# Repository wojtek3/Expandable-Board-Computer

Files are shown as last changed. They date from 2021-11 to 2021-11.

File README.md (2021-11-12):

# Board Computer display board

## General info
This project is a display for simple board computer dedicated for odl cars which didn't have it.

Board computer in Audi 80

## Base features
* ST7789 display
* EGT from K-type thermocouple
* AFR from analog input
* Control buttons
* I2C bus for more modules

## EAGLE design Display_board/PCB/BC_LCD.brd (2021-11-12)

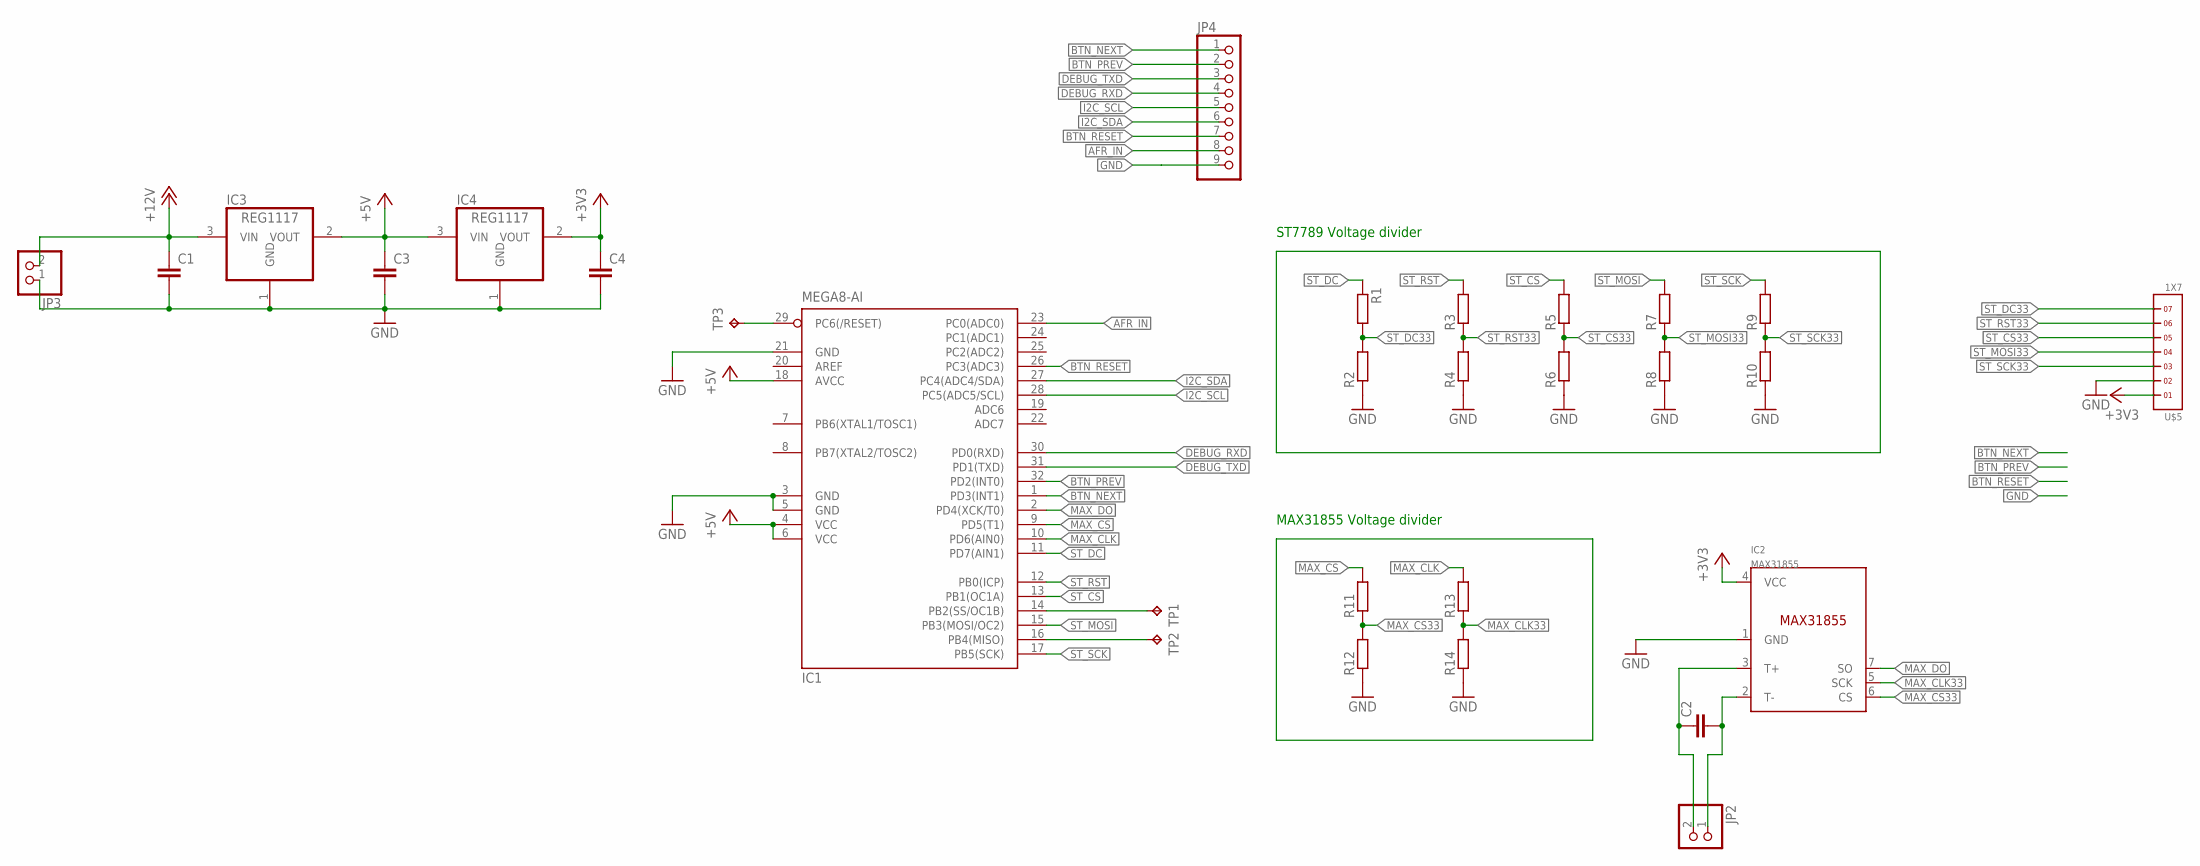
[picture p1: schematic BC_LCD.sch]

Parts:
C1, C2, C3, C4: C-EUC0805K; C0805K
IC1: MEGA8-AI; TQFP32-08
IC2: MAX31855; SOIC8
IC3, IC4: REG1117; SOT223
JP2, JP3: PINHD-1X2; 1X02
JP4: PINHD-1X9; 1X09
R1, R2, R3, R4, R5, R6, R7, R8, R9, R10, R11, R12, R13, R14: R-EU_M0805; M0805
TP1, TP2, TP3: TPTP12R; TP12R
U$5: 1X7

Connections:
+3V3: C4.1, IC2.4 (VCC), IC4.2 (VOUT), U$5.1
+5V: C3.1, IC1.4 (VCC), IC1.6 (VCC), IC1.18 (AVCC), IC3.2 (VOUT), IC4.3 (VIN)
+12V: C1.1, IC3.3 (VIN), JP3.2
AFR_IN: IC1.23 (PC0(ADC0)), JP4.8
BTN_NEXT: IC1.1 (PD3(INT1)), JP4.1
BTN_PREV: IC1.32 (PD2(INT0)), JP4.2
BTN_RESET: IC1.26 (PC3(ADC3)), JP4.7
DEBUG_RXD: IC1.30 (PD0(RXD)), JP4.4
DEBUG_TXD: IC1.31 (PD1(TXD)), JP4.3
GND: C1.2, C3.2, C4.2, IC1.3 (GND), IC1.5 (GND), IC1.21 (GND), IC2.1 (GND), IC3.1 (GND), IC4.1 (GND), JP3.1, JP4.9, R2.1, R4.1, R6.1, R8.1, R10.1, R12.1, R14.1, U$5.2
I2C_SCL: IC1.28 (PC5(ADC5/SCL)), JP4.5
I2C_SDA: IC1.27 (PC4(ADC4/SDA)), JP4.6
MAX_CLK: IC1.10 (PD6(AIN0)), R13.2
MAX_CLK33: IC2.5 (SCK), R13.1, R14.2
MAX_CS: IC1.9 (PD5(T1)), R11.2
MAX_CS33: IC2.6 (CS), R11.1, R12.2
MAX_DO: IC1.2 (PD4(XCK/T0)), IC2.7 (SO)
unnamed: C2.1, IC2.3 (T+), JP2.2
unnamed: C2.2, IC2.2 (T-), JP2.1
unnamed: IC1.14 (PB2(SS/OC1B)), TP1.TP
unnamed: IC1.16 (PB4(MISO)), TP2.TP
unnamed: IC1.29 (PC6(/RESET)), TP3.TP
ST_CS: IC1.13 (PB1(OC1A)), R5.2
ST_CS33: R5.1, R6.2, U$5.5
ST_DC: IC1.11 (PD7(AIN1)), R1.1
ST_DC33: R1.2, R2.2, U$5.7
ST_MOSI: IC1.15 (PB3(MOSI/OC2)), R7.2
ST_MOSI33: R7.1, R8.2, U$5.4
ST_RST: IC1.12 (PB0(ICP)), R3.2
ST_RST33: R3.1, R4.2, U$5.6
ST_SCK: IC1.17 (PB5(SCK)), R9.2
ST_SCK33: R9.1, R10.2, U$5.3

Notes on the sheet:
ST7789 Voltage divider
MAX31855 Voltage divider

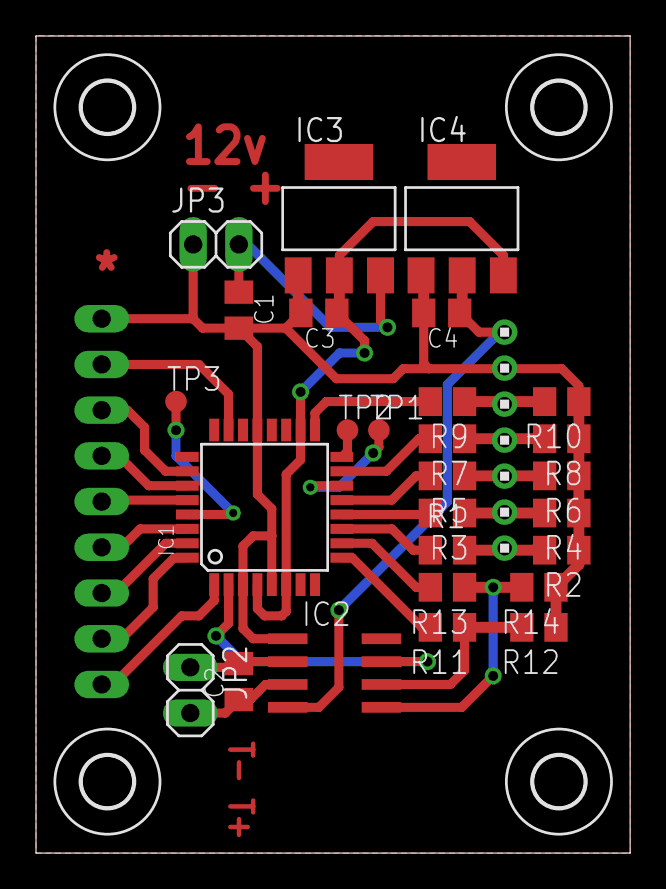
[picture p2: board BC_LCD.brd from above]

Board: 2 copper layers, 33.0 x 45.4 mm, 33 parts (1 on the bottom side), 32 nets.

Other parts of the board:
U$1, U$2, U$3, U$4: 2,8

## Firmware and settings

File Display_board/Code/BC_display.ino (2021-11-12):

void setup() {
  // put your setup code here, to run once:

}

void loop() {
  // put your main code here, to run repeatedly:

}/*
  ST7789 240x240 IPS (without CS pin) connections (only 6 wires required):
  #01 GND -> GND
  #02 VCC -> VCC (3.3V only!)
  #03 SCL -> D13/SCK
  #04 SDA -> D11/MOSI
  #05 RES -> D8
  #06 DC  -> D7
  #07 BLK -> NC

  MAX31855 K-Type thermocouple amplifier connections
  #01 VCC -> 3.3V
  #02 GND -> GND
  #03 SO  -> D4
  #04 CS  -> D5
  #05 SCK -> D6

  KEYS
  #01 PREV -> D2
  #02 NEXT -> D3
  #03 RESET ->D17 (A3)
*/

#include <SPI.h>
#include <Adafruit_GFX.h>
#include <Arduino_ST7789_Fast.h>
#include "Adafruit_MAX31855.h"

#define TFT_CS    9
#define TFT_DC    7
#define TFT_RST   8
#define SCR_WD   240
#define SCR_HT   240

#define MAXDO   4
#define MAXCS   5
#define MAXCLK  6

#define DEBOUNCE 30
#define NEXT_PIN 3
#define PREV_PIN 2
#define RESET_PIN 17

#define NUM_MODES 2 //starting from 0

Arduino_ST7789 tft = Arduino_ST7789(TFT_DC, TFT_RST, TFT_CS);
Adafruit_MAX31855 thermocouple(MAXCLK, MAXCS, MAXDO);

bool linesDrawn = false;

float rawAFR, nowAFR, minAFR = 20, maxAFR = 10;
int nowEGT, minEGT = 2000, maxEGT = 10;
unsigned long lastTimeEGT = 0, lastTimeAFR = 0;

int nextLast, prevLast, resetLast;
short mode = 0;

void setup(void)
{
  tft.init(SCR_WD, SCR_HT);
  tft.setRotation(1);

  pinMode(NEXT_PIN, INPUT_PULLUP);
  pinMode(PREV_PIN, INPUT_PULLUP);
  pinMode(RESET_PIN, INPUT_PULLUP);
}

void loop() {
  //===================== MODE SELECT ========================
  if (digitalRead(NEXT_PIN) == 0 && nextLast == 1) {
    mode++;
    if (mode > NUM_MODES) mode = 0;
    nextLast = 0;
    linesDrawn = false;
    delay(DEBOUNCE);
  }
  if (digitalRead(NEXT_PIN) == 1) nextLast = 1;

  if (digitalRead(PREV_PIN) == 0 && prevLast == 1) {
    mode--;
    if (mode < 0) mode = 1;
    prevLast = 0;
    linesDrawn = false;
    delay(DEBOUNCE);
  }
  if (digitalRead(PREV_PIN) == 1) prevLast = 1;

  //======================= RESET ============================
  if (digitalRead(RESET_PIN) == 0 && resetLast == 1) {
    if(mode == 0){
      minEGT = 1000;
      maxEGT = 0;
    }
    if(mode == 1 || mode == 2){
      minAFR = 25;
      maxAFR = 1;
    }
    resetLast = 0;
    delay(DEBOUNCE);
  }
  if (digitalRead(RESET_PIN) == 1) resetLast = 1;
  
  //===================== MODE0 EGT ==========================
  if (millis() - lastTimeEGT > 200) {
    nowEGT = thermocouple.readCelsius();
    if (isnan(nowEGT)) {
      tft.fillScreen(BLACK);
      tft.setTextSize(4);
      tft.setCursor(87, 30);
      tft.print("BLAD");
      tft.setCursor(47, 50);
      tft.print("TERMOPARY");
    } else {
      if (nowEGT < minEGT) minEGT = nowEGT;
      if (nowEGT > maxEGT) maxEGT = nowEGT;
      if (mode == 0) EGT_show(nowEGT, minEGT, maxEGT);
    }
    lastTimeEGT = millis();
  }
  //===================== MODE1-2 AFR ==========================
  if (millis() - lastTimeAFR > 100) {
    rawAFR = analogRead(A0);
    if (mode == 1) {
      nowAFR = (map(rawAFR, 0, 1023, 1090, 2020)) / 100.0;
      if (nowAFR < minAFR) minAFR = nowAFR;
      if (nowAFR > maxAFR) maxAFR = nowAFR;
      AFR_show(nowAFR, minAFR, maxAFR, 0);
    }
    if (mode == 2) {
      nowAFR = (map(rawAFR, 0, 1023, 1029, 1911)) / 100.0;
      if (nowAFR < minAFR) minAFR = nowAFR;
      if (nowAFR > maxAFR) maxAFR = nowAFR;
      AFR_show(nowAFR, minAFR, maxAFR, 1);
    }
    lastTimeAFR = millis();
  }
}

void AFR_show(float nowAFR, float minAFR, float maxAFR, byte fuel) {
  if (linesDrawn == false) draw_lines();

  if (fuel == 1) {
    tft.setCursor(54, 5);
    tft.setTextColor(RED, BLACK);
    tft.setTextSize(4);
    tft.print("AFR PB");
  }
  else{
    tft.setCursor(43, 5);
    tft.setTextColor(RED, BLACK);
    tft.setTextSize(4);
    tft.print("AFR LPG");
  }
  
  tft.setCursor(5, 175);
  tft.setTextSize(2);
  tft.print("MIN");

  tft.setCursor(125, 175);
  tft.setTextSize(2);
  tft.print("MAX");

  tft.setCursor(10, 70);
  tft.setTextSize(9);
  tft.print(nowAFR, 1);

  tft.setCursor(10, 198);
  tft.setTextSize(4);
  tft.print(minAFR, 1);

  tft.setCursor(130, 198);
  tft.setTextSize(4);
  tft.print(maxAFR, 1);
}

void EGT_show(int nowEGT, int minEGT, int maxEGT) {
  if (linesDrawn == false) draw_lines();

  tft.setCursor(87, 5);
  tft.setTextColor(RED, BLACK);
  tft.setTextSize(4);
  tft.print("EGT");

  //tft.setCursor(5, 175);
  //tft.setTextSize(2);
  //tft.print("MIN");

  tft.setCursor(125, 175);
  tft.setTextSize(2);
  tft.print("MAX");

  tft.setCursor(40, 70);
  tft.setTextSize(9);
  tft.print(nowEGT, 1);

  //tft.setCursor(23, 198);
  //tft.setTextSize(4);
  //tft.print(minEGT, 1);

  tft.setCursor(145, 198);
  tft.setTextSize(4);
  tft.print(maxEGT, 1);
}

void draw_lines() {
  tft.fillScreen(BLACK);
  tft.drawFastHLine(0, 40, tft.width(), RED);
  tft.drawFastHLine(0, 41, tft.width(), RED);
  tft.drawFastHLine(0, 170, tft.width(), RED);
  tft.drawFastHLine(0, 171, tft.width(), RED);
  tft.drawFastVLine(120, 170, tft.width(), RED);
  tft.drawFastVLine(121, 171, tft.width(), RED);
  linesDrawn = true;
}
